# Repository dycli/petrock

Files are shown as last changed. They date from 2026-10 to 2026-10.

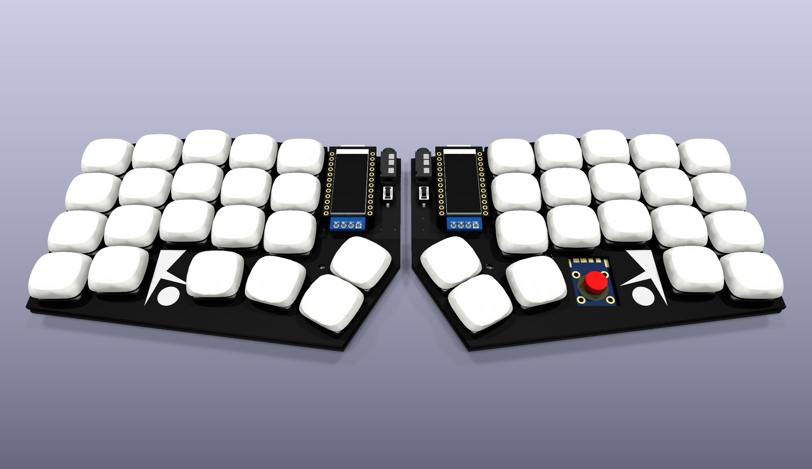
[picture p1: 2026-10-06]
demo/12-assembled.png

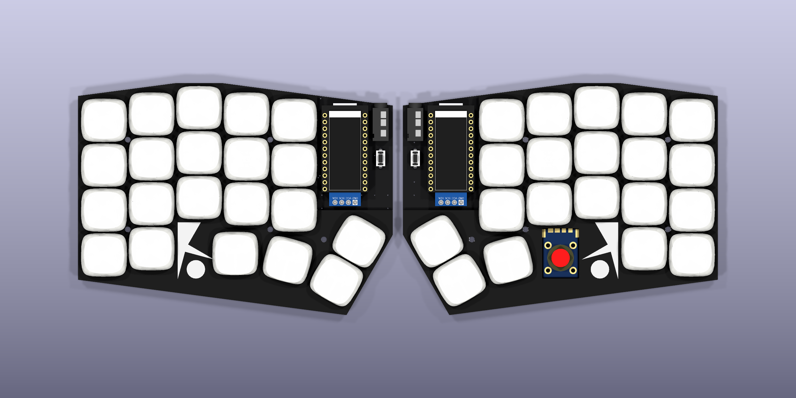
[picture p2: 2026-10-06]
demo/14-assembled-top.png

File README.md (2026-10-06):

# Petrock

A split choc keyboard with a trackpoint in place of an outer thumb key:
**Petrock-41** has one, at the right thumb; **Petrock-40** has one on each half;
**Petrock-42** has none, a key at both outer thumbs.

Based on holykeebs' Corne Choc PCB and plate from
[idank/keyboards](https://github.com/idank/keyboards) (`corne/choc`, commit
f149b9b), licensed CC-BY-SA-4.0. This derivative uses the same licence.

## Changes from the Corne Choc

The board is built from the stock file: its parts move to the new layout, and
every wire is then drawn afresh by rule (see Build). The stock schematic's
connections stay, apart from the thumbs' columns (see Firmware).

- **No lighting.** Every per-key and underglow LED, the LED supply diodes and
  the LED wiring are gone (`tools/no_leds.py`). An RGB version may follow.
- **Exact stagger.** Rows exactly 17 mm apart, each column's top key a whole
  number of 2.37 mm steps below the middle finger's (`tools/stagger.py`;
  stock is off by up to 0.02 mm).
- **Five columns.** The outer pinky column goes. The pinky column moves up to
  one step below the ring column and gains a fourth key (the old outer top
  key); the ring column gains one too (the old outer bottom key). Each joins
  the column wire it lands on, in the thumb row (row 3).
- **Thumb cluster.** Each thumb key turns 15 degrees from its neighbour about a
  hinge where their facing corners sit 0.5 mm apart, starting from the bottom
  inner-index key (`tools/thumbs.py`). The 1.5u inner key becomes two 1u keys;
  the new upper one takes the thumb row's last free column (col 0).
- **Trackpoint.** Sprintek SK8707-01-004 at the outer thumb key: sensor on the
  front, nub centred on where the key was, driver on the back, PS/2 clock and
  data on controller pins 1/2, 3.3 V from the OLED header; sensor A1/A3, controller
  board A2/A4 (`tools/outer_thumb.py`, footprints from `tools/make_footprints.py`).
- **Pins for wireless.** Pins 1/2 are a nice!nano's high-frequency D1/D0, which
  the ZMK PS/2 driver recommends (lower-frequency pins can disturb Bluetooth);
  the TRRS data line moves from pin 2 to pin 11 to free them (`tools/pins.py`).
- **Outline.** Drawn from the keys (`tools/outline.py`): a flat top 1.15 mm
  above the middle column, 7.5-degree slopes to either side, a straight outer
  side, one 7.5-degree bottom edge, and the inner side widened for the upper
  thumb key (`tools/widen.py`). Keycaps sit 1.15 mm from the edge wherever it
  follows them.
- **Controller corner.** Across the strip between the inner index keycaps
  and the inner edge, the controller (a nice!nano's 17.78 mm board) and the
  jack's 6 mm body sit with three even 1.63 mm gaps; each drops until its square
  top corner is 1.15 mm inside the inner slope, like the keycaps. The USB-C and
  the jack's barrel overhang. The reset button sits under the jack
  (`tools/inner_strip.py`).
- The holykeebs and Corne logos and holykeebs' revision stamp are removed; the back
  carries the short hash of the commit the board was built from, between each
  controller's pin rows (`tools/stamp.py`; the build won't stamp uncommitted
  scripts); the board and the switch plates
  carry the Petrock logo with a 7 mm dot in its notch (`tools/logo.py`), and the
  jack, reset button and OLED header have no printed outlines
  (`tools/quiet_silk.py`).
- Five standoffs per half, as stock, placed by geometry (`tools/standoffs.py`):
  four where four keys meet, each at the four keys' centre, forming a 54 x 34 mm
  rectangle (pinky and ring columns, and index and inner index columns, each
  between their top two rows and below their third); and one at the thumbs,
  equally far from its three keycap corners. A key diode may move a fraction to
  make room, if it stays clear. The switch plate has a screw hole over each
  (`tools/plate.py`), as stock.
- Plates regenerated (`tools/plate.py`): the right one (both, on Petrock-40;
  neither, on Petrock-42) has an opening for the trackpoint sensor; a new FR4 bottom plate fits the
  outline.

## Build

`tools/build.sh [single|dual|none]` regenerates a board from the stock file:

1. **Place:** strip the lighting, then move every part to the layout
   (`tools/parts.py drag`).
2. **Route by rule** (`tools/route.py`), as a careful hand would: each column a
   straight line up the front through its switch pins; each row a line along
   the back under its keys, stepping 45 degrees in the gap between columns;
   every diode in the same place beside its key with the same two short links;
   the column wires gathered into an evenly spaced bus in the gap under the
   middle row and fanned into the controller in a staircase; the trackpoint
   wires and power in a bundle up the lane between the middle and index
   columns and along the top edge; every bend 45 degrees, no right angles
   except where a wire joins another. Then ground is poured on both sides and
   stitched together with vias (`tools/stitch.py`).
3. **Check:** the build fails unless DRC finds nothing but the stock
   footprints' library notices and every connection is made.

Then `tools/plates.sh` makes the plates (order the switch plates at 1.2 mm,
which choc switches clip into; the main board and bottom plate at 1.6 mm; all
in HASL, the cheapest finish: the trackpoint driver's pads are hand-soldered
and wide enough that ENIG's flatness isn't needed)
and the 1:1 printout (print it with
scaling off, e.g. `lp -o print-scaling=none`). `tools/fab.sh [single|dual|none]`
writes Gerber and drill zips and JLC's assembly BOM and placement (diodes and
hot-swap sockets) to `fab/`; `tools/demo.sh` renders `demo/`. All need KiCad 10.

Outputs: `pcb/petrock-41*.kicad_pcb` and `pcb/bottom.kicad_pcb`;
`pcb/dual/petrock-40*.kicad_pcb` and `pcb/dual/bottom.kicad_pcb`;
`pcb/none/petrock-42*.kicad_pcb` and `pcb/none/bottom.kicad_pcb`.

## Assembly

The stack, per standoff: a top screw through the switch plate's 2.1 mm hole
into a spacer that passes through the main board's 3.1 mm hole down to the
bottom plate, where a bottom screw holds it. The switch plate and bottom plate
clamp the spacers; the main board hangs from the switches (clipped into the
plate, pins in the hot-swap sockets), 1.0 mm under the plate.

- 10 round M2 x 5 mm female-female spacers, 3.0 mm across (knurled brass ones
  are common; hex ones don't pass the 3.1 mm holes). 5 mm, not holykeebs' 4 mm:
  it leaves 2.4 mm under the main board for the sockets (1.85 mm) and the
  trackpoint drivers (about 2.1 mm).
- Top screws (they sit on the plate, beside the switches): the four where four
  keys meet sit between switch housings (15 mm square on an 18 x 17 mm grid),
  so their heads must be about 3.0 mm across or less: M2 low small-head socket
  screws (e.g. MISUMI's; check the listed head diameter), or M1.6 socket caps
  (3.0 mm heads) with M1.6 spacers at those four. The thumb one and the 10
  underneath: ordinary low M2 x 3 mm screws (e.g. ISO 7380, holykeebs').
- Order: spacers up through the main board, bottom plate on; switch plate on
  and its screws in; then the switches, which draw the main board up as they seat.
- Rubber feet: near the standoffs, and two along the bottom edge (by the outer
  corner and under the trackpoint), which has no standoff.

## Firmware

- Matrix (each half, right with `_r` nets): rows 0-2 are the three full rows,
  columns 1-5 pinky to inner index. Row 3 is the bottom pinky key (col 1), the
  bottom ring key (col 2) and the thumbs, outer to inner: col 3, col 4, col 5.
  Col 0 is unused, except on a half with four thumbs (the 41's left, both of
  the 42's): there the extra outermost one (in the trackpoint's place) is col
  3, the next two col 4 and col 5, and the innermost col 0.
- Wired (QMK, RP2040 Pro Micro): split serial on pin 11 (`SOFT_SERIAL_PIN GP8`,
  PIO driver); PS/2 `PS2_CLOCK_PIN GP0`, `PS2_DATA_PIN GP1` (PIO driver).
- Wireless (ZMK, nice!nano): PS/2 clock D1 (P0.06), data D0 (P0.08), e.g. with
  infused-kim's PS/2 mouse driver; the trackpoint's driver board resets itself,
  so no reset pin. It draws power from the controller's VCC pin, which ZMK's
  external-power control switches off in sleep. The battery solders to the
  nice!nano's B+/B- pads (no switch on the board). The jack isn't used.
- The sensor's pad edge faces the controller (if the axes come out turned,
  rotate them in firmware). No RGB.

## Open items

- **Driver footprint:** Sprintek doesn't draw the detached driver on its own.
  Its outline and sensor-link pads follow the integrated-module drawing. Its
  host pins disagree between the drawing (1.80 mm pitch) and holykeebs'
  product photos (1.72 mm), so their pads fit both: 1.758 mm pitch about the
  row's shared middle, every pin within 0.21 mm of its pad's centre either
  way. Check a real driver against the footprint before ordering boards.
- **Under-board height:** check that the driver (about 2 mm) clears the
  bottom plate.
- **Standoff length** for the plate/PCB/bottom sandwich (M2 3 mm both sides
  expected for the 1.6 mm FR4 bottom).
- **Schematic:** still the Corne Choc's.

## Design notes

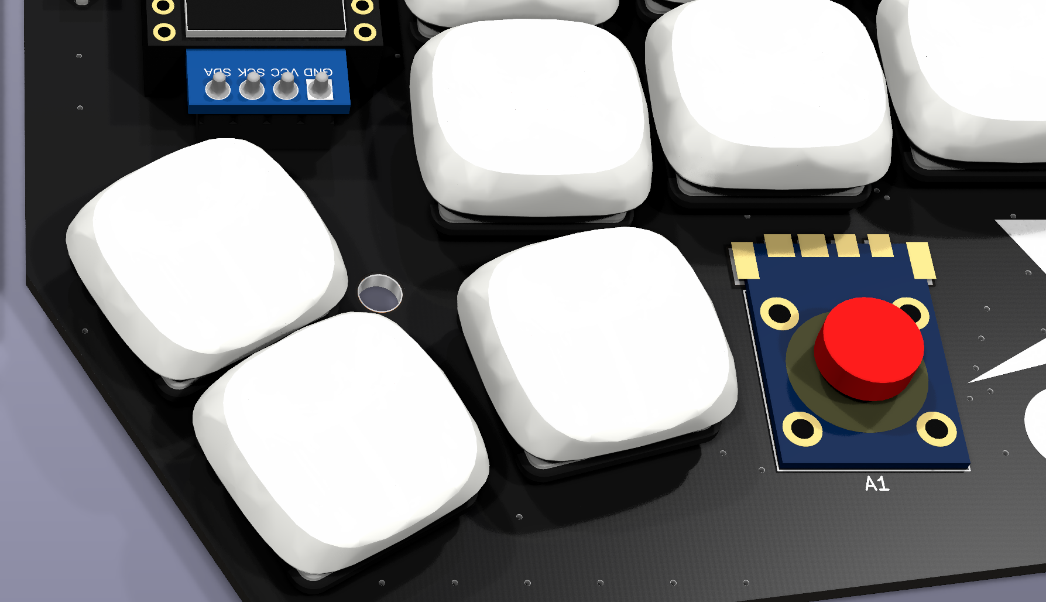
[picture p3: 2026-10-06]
demo/03-trackpoint-closeup.png

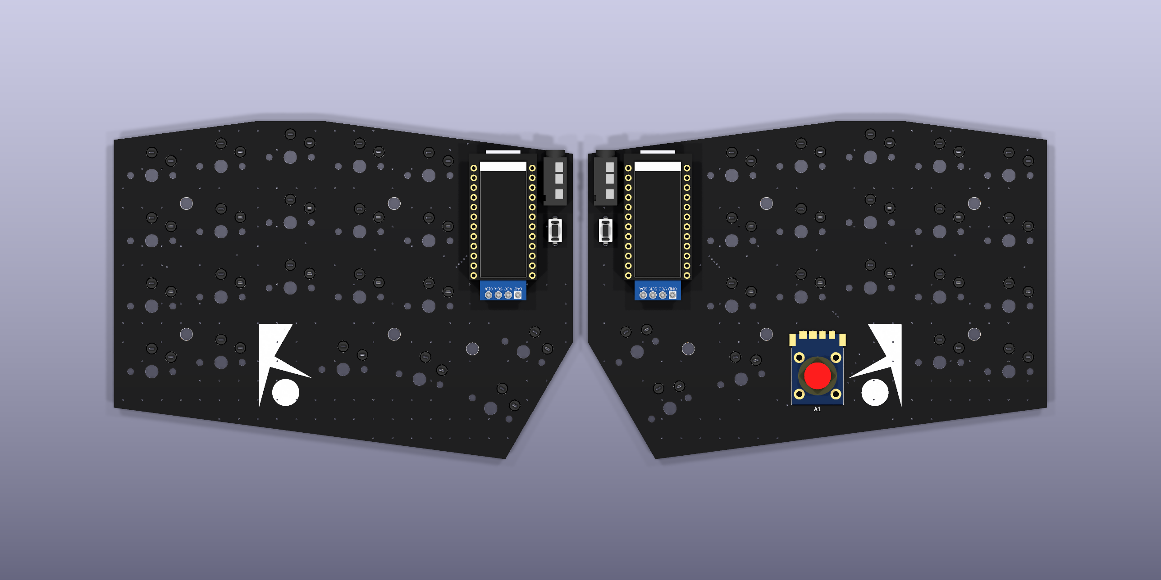
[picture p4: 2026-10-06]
demo/04-bare-front.png

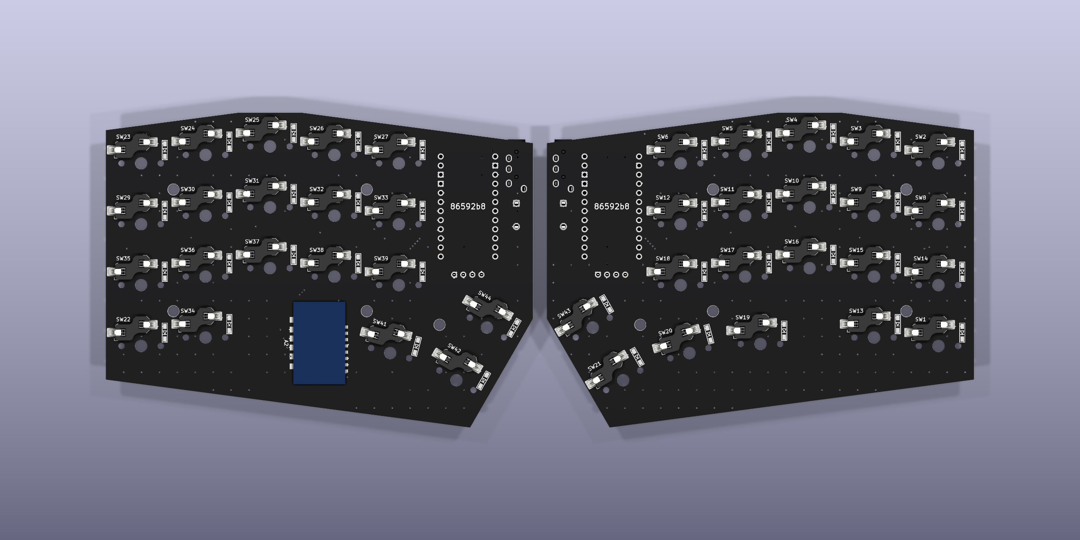
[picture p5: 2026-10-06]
demo/05-bare-back.png

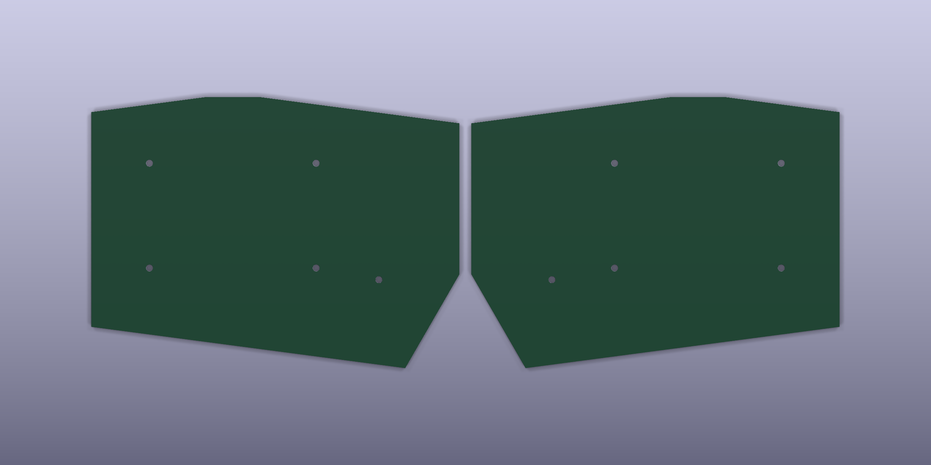
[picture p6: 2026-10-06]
demo/08-bottom-plate.png

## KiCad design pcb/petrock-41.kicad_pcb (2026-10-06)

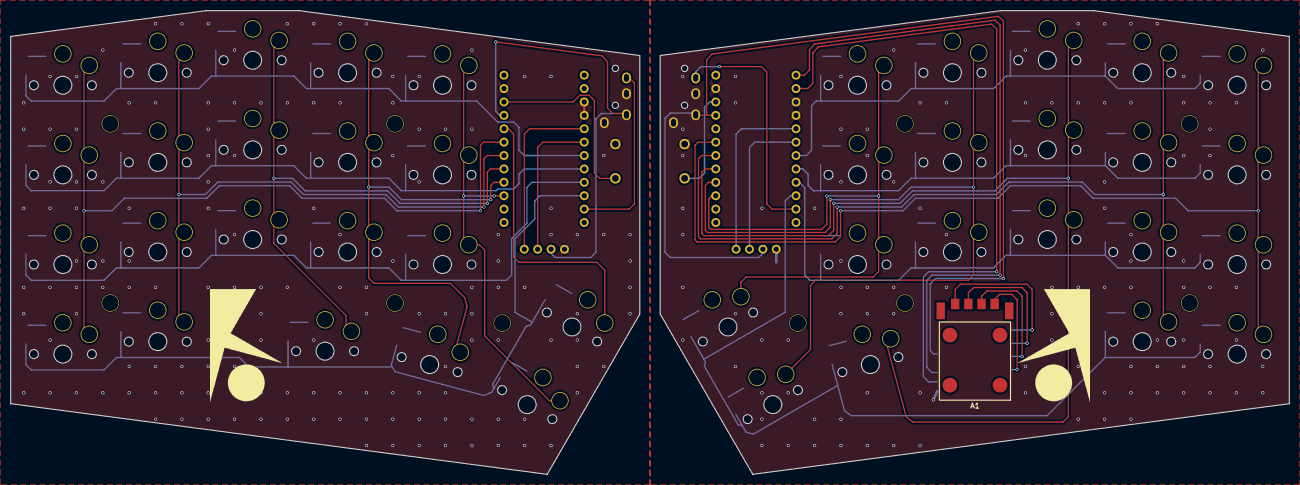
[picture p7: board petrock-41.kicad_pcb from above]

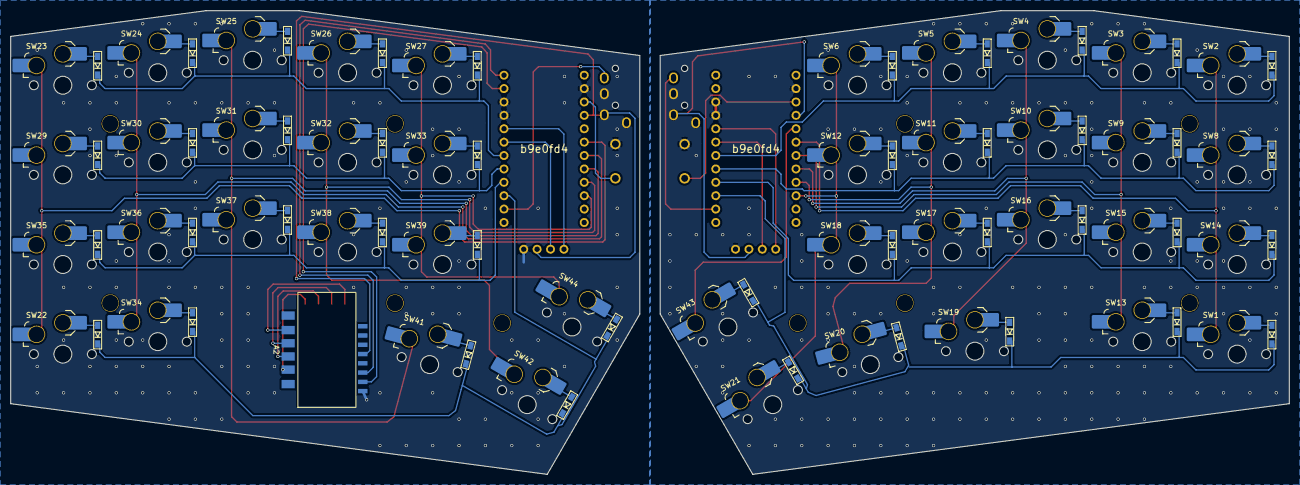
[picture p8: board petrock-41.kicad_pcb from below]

Board: 2 copper layers, 242.5 x 87.9 mm, 100 parts (87 on the bottom side), 78 nets.

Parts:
A1: SK8707-01 sensor; SK8707-01_sensor
A2: SK8707-01 driver; SK8707-01_driver
D1, D2, D3, D4, D5, D6, D8, D9, D10, D11, D12, D13, D14, D15, D16, D17, D18, D19, D20, D21, D22, D23, D24, D25, D26, D27, D29, D30, D31, D32, D33, D34, D35, D36, D37, D38, D39, D41, D42, D45, D46: D; D3_SMD_v2
J1, J3: MJ-4PP-9; MJ-4PP-9_1side
J2, J4: OLED; OLED_1side_1mm_holes
RSW1, RSW2: SW_PUSH; ResetSW_1side
SW1, SW2, SW3, SW4, SW5, SW6, SW8, SW9, SW10, SW11, SW12, SW13, SW14, SW15, SW16, SW17, SW18, SW19, SW20, SW21, SW22, SW23, SW24, SW25, SW26, SW27, SW29, SW30, SW31, SW32, SW33, SW34, SW35, SW36, SW37, SW38, SW39, SW41, SW42, SW43, SW44: SW_PUSH; SW_choc_v1_HS_CPG135001S30_1u
U1, U2: ProMicro; ProMicro_1mm_holes
h2, h2#2, h2#3, h2#4, h2#5, h2#6, h2#7, h2#8: h2; M2_SPACER

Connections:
GND: J1.C, J2.4, RSW1.2, U1.3 (GND), U1.4 (GND), U1.23 (GND)
GNDA: A2.1, J3.C, J4.4, RSW2.2, U2.3 (GND), U2.4 (GND), U2.23 (GND)
unnamed: D1.2 (A), SW1.2
unnamed: D2.2 (A), SW2.2
unnamed: D3.2 (A), SW3.2
unnamed: D4.2 (A), SW4.2
unnamed: D5.2 (A), SW5.2
unnamed: D6.2 (A), SW6.2
unnamed: D8.2 (A), SW8.2
unnamed: D9.2 (A), SW9.2
unnamed: D10.2 (A), SW10.2
unnamed: D11.2 (A), SW11.2
unnamed: D12.2 (A), SW12.2
unnamed: D13.2 (A), SW13.2
unnamed: D14.2 (A), SW14.2
unnamed: D15.2 (A), SW15.2
unnamed: D16.2 (A), SW16.2
unnamed: D17.2 (A), SW17.2
unnamed: D18.2 (A), SW18.2
unnamed: D19.2 (A), SW19.2
unnamed: D20.2 (A), SW20.2
unnamed: D21.2 (A), SW21.2
unnamed: D22.2 (A), SW22.2
unnamed: D23.2 (A), SW23.2
unnamed: D24.2 (A), SW24.2
unnamed: D25.2 (A), SW25.2
unnamed: D26.2 (A), SW26.2
unnamed: D27.2 (A), SW27.2
unnamed: D29.2 (A), SW29.2
unnamed: D30.2 (A), SW30.2
unnamed: D31.2 (A), SW31.2
unnamed: D32.2 (A), SW32.2
unnamed: D33.2 (A), SW33.2
unnamed: D34.2 (A), SW34.2
unnamed: D35.2 (A), SW35.2
unnamed: D36.2 (A), SW36.2
unnamed: D37.2 (A), SW37.2
unnamed: D38.2 (A), SW38.2
unnamed: D39.2 (A), SW39.2
unnamed: D41.2 (A), SW41.2
unnamed: D42.2 (A), SW42.2
unnamed: D45.2 (A), SW43.2
unnamed: D46.2 (A), SW44.2
SCL: J2.2, U1.6 (3/D0/SCL)
SCL_r: J4.2, U2.6 (3/D0/SCL)
SDA: J2.1, U1.5 (2/D1/SDA)
SDA_r: J4.1, U2.5 (2/D1/SDA)
TP_CLK: A2.3, U2.1 (TX0/D3)
TP_DATA: A2.2, U2.2 (RX1/D2)
TP_S1: A1.S1, A2.S1
TP_S2: A1.S2, A2.S2
TP_S3: A1.S3, A2.S3
TP_S4: A1.S4, A2.S4
VCC: J1.D, J2.3, U1.21 (VCC)
VDD: A2.5, J3.D, J4.3, U2.21 (VCC)
col0: SW43.1, U1.20 (F4/A3)
col1: SW1.1, SW2.1, SW8.1, SW14.1, U1.19 (F5/A2)
col1_r: SW22.1, SW23.1, SW29.1, SW35.1, U2.19 (F5/A2)
col2: SW3.1, SW9.1, SW13.1, SW15.1, U1.18 (F6/A1)
col2_r: SW24.1, SW30.1, SW34.1, SW36.1, U2.18 (F6/A1)
col3: SW4.1, SW10.1, SW16.1, SW19.1, U1.17 (F7/A0)
col3_r: SW25.1, SW31.1, SW37.1, SW41.1, U2.17 (F7/A0)
col4: SW5.1, SW11.1, SW17.1, SW20.1, U1.16 (B1/15)
col4_r: SW26.1, SW32.1, SW38.1, SW42.1, U2.16 (B1/15)
col5: SW6.1, SW12.1, SW18.1, SW21.1, U1.15 (B3/14)
col5_r: SW27.1, SW33.1, SW39.1, SW44.1, U2.15 (B3/14)
data: J1.B, U1.11 (8/B4)
data_r: J3.B, U2.11 (8/B4)
reset: RSW1.1, U1.22 (RST)
reset_r: RSW2.1, U2.22 (RST)
row0: D2.1 (K), D3.1 (K), D4.1 (K), D5.1 (K), D6.1 (K), U1.7 (4/D4)
row0_r: D23.1 (K), D24.1 (K), D25.1 (K), D26.1 (K), D27.1 (K), U2.7 (4/D4)
row1: D8.1 (K), D9.1 (K), D10.1 (K), D11.1 (K), D12.1 (K), U1.8 (5/C6)
row1_r: D29.1 (K), D30.1 (K), D31.1 (K), D32.1 (K), D33.1 (K), U2.8 (5/C6)
row2: D14.1 (K), D15.1 (K), D16.1 (K), D17.1 (K), D18.1 (K), U1.9 (6/D7)
row2_r: D35.1 (K), D36.1 (K), D37.1 (K), D38.1 (K), D39.1 (K), U2.9 (6/D7)
row3: D1.1 (K), D13.1 (K), D19.1 (K), D20.1 (K), D21.1 (K), D45.1 (K), U1.10 (7/E6)
row3_r: D22.1 (K), D34.1 (K), D41.1 (K), D42.1 (K), D46.1 (K), U2.10 (7/E6)

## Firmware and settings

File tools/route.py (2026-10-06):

"""Route the board by rule, as by hand: columns straight up the front, rows
along the back under each key, the same short diode links on every key, and
the column wires gathered into an even bus to the controller. Handles both
boards: the 40 (trackpoint on each half) and the 41 (extra thumb key on the left).

usage: route.py IN OUT
"""
import os
import sys

import pcbnew

SRC, OUT = sys.argv[1:3]
b = pcbnew.LoadBoard(SRC)                # bare of tracks (tools/clear_copper.py): every wire is drawn here
MM = pcbnew.FromMM
F, B = pcbnew.F_Cu, pcbnew.B_Cu
W = 0.25                 # signal width
ROW_DY = 3.0             # row line below each key centre
COL_DX = 4.0             # column line right of each key centre (passes left of the side hole)
BUS_DY = 4.4             # first bus wire below the row-0 key centre
BUS_PITCH = 0.65


def fp(ref):
    return b.FindFootprintByReference(ref)


def pad(ref, num, tht=None):
    """Position (mm) of a part's pad; tht=True picks the plated hole one."""
    for p in fp(ref).Pads():
        if p.GetNumber() == num and (tht is None or (p.GetAttribute() == pcbnew.PAD_ATTRIB_PTH) == tht):
            return pcbnew.ToMM(p.GetPosition().x), pcbnew.ToMM(p.GetPosition().y)
    raise KeyError((ref, num))


def net(ref, num):
    for p in fp(ref).Pads():
        if p.GetNumber() == num:
            return p.GetNet()


def track(n, layer, pts, w=W):
    for (x1, y1), (x2, y2) in zip(pts, pts[1:]):
        if (x1, y1) == (x2, y2):
            continue
        t = pcbnew.PCB_TRACK(b)
        t.SetStart(pcbnew.VECTOR2I(MM(x1), MM(y1)))
        t.SetEnd(pcbnew.VECTOR2I(MM(x2), MM(y2)))
        t.SetWidth(MM(w))
        t.SetLayer(layer)
        t.SetNet(n)
        b.Add(t)


def via(n, p):
    v = pcbnew.PCB_VIA(b)
    v.SetPosition(pcbnew.VECTOR2I(MM(p[0]), MM(p[1])))
    v.SetWidth(MM(0.6))
    v.SetDrill(MM(0.4))
    v.SetNet(n)
    b.Add(v)


def jog(x0, y0, x1, y1):
    """Horizontal from (x0,y0) to (x1,y1) with one 45-degree step at the end."""
    dy = y1 - y0
    s = 1 if x1 >= x0 else -1
    return [(x0, y0), (x1 - s * abs(dy), y0), (x1, y1)]


import math

DIODE = (-6.6, -3.7)     # diode centre from its key centre: anode within socket pad 2's height, clear of the standoffs


def local(key):
    """Map key-local mm offsets (unrotated key, y down) onto the board."""
    f = fp(key)
    cx, cy = pcbnew.ToMM(f.GetPosition().x), pcbnew.ToMM(f.GetPosition().y)
    t = math.radians(f.GetOrientationDegrees())
    return lambda x, y: (cx + x * math.cos(t) + y * math.sin(t), cy - x * math.sin(t) + y * math.cos(t))


# Every diode in the same place beside its key.
for f in list(b.GetFootprints()):
    r = f.GetReference()
    if not r.startswith("SW") or not net(r, "2").GetNetname().startswith("Net-(D"):
        continue
    an = net(r, "2").GetNetname()
    d = fp(an[len("Net-("):an.index("-A")])
    x, y = local(r)(*DIODE)
    d.SetPosition(pcbnew.VECTOR2I(MM(x), MM(y)))
    d.SetOrientationDegrees(90 + f.GetOrientationDegrees())

DUAL = any(f.GetReference() == "A4" for f in b.GetFootprints())   # a trackpoint on the left (the 40)
RTP = any(f.GetReference() == "A2" for f in b.GetFootprints())    # a trackpoint on the right (the 40 and 41)

# ---- the key matrix of the left half ------------------------------------
# Main keys: socket unrotated, diode to its left. Columns by x, rows by y.
keys = {}
for f in b.GetFootprints():
    r = f.GetReference()
    if r.startswith("SW") and f.GetOrientationDegrees() == 0 and pcbnew.ToMM(f.GetPosition().x) < 155:
        keys[r] = (pcbnew.ToMM(f.GetPosition().x), pcbnew.ToMM(f.GetPosition().y))
diode_of = {}
for r in keys:
    anode = net(r, "2").GetNetname()            # e.g. Net-(D2-A)
    diode_of[r] = anode[len("Net-("):anode.index("-A")]

xs = [round(x, 2) for x, _ in keys.values()]
keys = {r: p for r, p in keys.items() if xs.count(round(p[0], 2)) >= 3}   # the 41's extra thumb has no column
cols = sorted({round(x, 2) for x, _ in keys.values()})
grid = {}                                       # (col, row) -> ref, for rows 0..2
for r, (x, y) in keys.items():
    c = cols.index(round(x, 2))
    grid.setdefault(c, []).append((y, r))
for c in grid:
    grid[c].sort()

main = {}                                       # (c, row) -> ref for the 3 full rows
for c, ys in grid.items():
    for i, (y, r) in enumerate(ys[:3]):
        main[(c, i)] = r

# Diode links: anode straight across to the socket's pad 2; cathode straight
# down to the row line under the key.
for (c, i), r in main.items():
    cx, cy = keys[r]
    d = diode_of[r]
    ax, ay = pad(d, "2")
    kx, ky = pad(d, "1")
    track(net(d, "2"), B, [(ax, ay), (cx - 3.24, ay)])
    track(net(d, "1"), B, [(cx - 7.0, ky), (cx - 7.0, cy + ROW_DY)])

# Rows 0..2: one line under the keys, a 45-degree step between columns.
rows_end = {}
for i in range(3):
    n = net(diode_of[main[(0, i)]], "1")
    pts = []
    for c in range(len(cols)):
        cx, cy = keys[main[(c, i)]]
        y = cy + ROW_DY
        if not pts:
            pts.append((cx - 7.0, y))
        else:                              # a 45-degree step centred on the gap between the keys
            x0, y0 = pts[-1]
            gap = cols[c] - 9.0
            h = abs(y - y0) / 2
            pts += [(gap - h, y0), (gap + h, y), (cx - 7.0, y)]
    rows_end[i] = (n, pts)

# Columns: straight down the front through every switch pin of the column.
for c in range(len(cols)):
    ys = grid[c]
    top, bot = ys[0][1], ys[-1][1]
    x = cols[c] + COL_DX
    n = net(top, "1")
    track(n, F, [(x, pad(top, "1", tht=True)[1]), (x, pad(bot, "1", tht=True)[1])])

# ---- into the controller --------------------------------------------------
U = "U1"


def pin_of(netname):
    for p in fp(U).Pads():
        if p.GetNetname() == netname:
            return pcbnew.ToMM(p.GetPosition().x), pcbnew.ToMM(p.GetPosition().y)
    raise KeyError(netname)


LEFT_PINS = pin_of("col0")[0]            # the controller's pin row facing the keys
GAP = 0.65                               # an even step between neighbouring wires

# Rows: through the gap between two near-side pins, then across underneath the
# controller to their own pin on the far side.
INSIDE = LEFT_PINS + 2.84                # first wire lane inside the controller
for i, (n, pts) in rows_end.items():
    px, py = pin_of(n.GetNetname())
    x, y = pts[-1]
    if i < 2:
        gy = py - 6.35 if i == 0 else py + 3.81      # half way between two near-side pins
        pts += jog(x, y, LEFT_PINS - 1.2, gy)[1:]
        pts += [(INSIDE, gy), (INSIDE, py + (1 if gy > py else -1)), (INSIDE + 1, py), (px, py)]
    else:
        # Below the controller's last pin, then up the inside.
        lane = INSIDE + 1.5 * (i - 1)
        drop = LEFT_PINS + 1.45 + 0.65 * (i - 2)
        pts += [(drop, y), (drop, 95.0)]
        pts += [(lane, 95.0 - (lane - drop)), (lane, py + 1), (lane + 1, py), (px, py)]
    track(n, B, pts)
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

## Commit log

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2026-10-03 Right-thumb trackpoint: widen inner edges, jacks to top edge, module header TP1
    Generated by tools/build.sh from the upstream board. SW42, D42 and the right
    OLED header are removed; TP1 (Pro Micro pattern, pins 5/6/21/23 wired to
    GP2/GP3/3V3/GND) takes the thumb spot. Both halves widen 6.2 mm on the inner
    edge so the TRRS jacks face the top edge beside the controllers. DRC matches
    upstream apart from pre-existing LED cutout warnings.
    [corne choc.kicad_pcb]
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2026-10-03 Trackpoint at the right outer thumb key with an SK8707-01 sensor and driver
    Replaces the earlier holykeebs-module design. The board is stock except at
    SW40: switch, diode and hidden LED removed (RGB chain bridged), sensor on the
    front at the key centre, driver on the back beneath it, PS/2 to U2 pins 11/12
    (GP8/GP9). Routing uses a small grid router; DRC matches upstream apart from
    pre-existing LED-cutout warnings.
    [bottom.kicad_pcb, corne choc plate.kicad_pcb, corne choc.kicad_pcb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]
2026-10-03 Driver footprint from holykeebs' top-view photo: 23 x 14.5 mm, wider host pads
    The photo shows the detached driver is the full 14.5 mm control board and
    confirms the sensor-link pad pitch and order. Driver moved to fit; routes now
    name pads instead of coordinates; router keeps 0.3 mm from holes.
    [corne choc.kicad_pcb]
2026-10-03 v2: wider inner edges, jacks at the top, split inner thumb keys, peaked top edges
    Both halves widen 6.2 mm inward with the TRRS jacks facing the top edge; each
    inner 1.5u thumb becomes two 1u keys at the same angle (new key on col2, with
    diode and LED in the chain); edges sit 0.95 mm from the inner thumb keycaps;
    top edges peak at the middle-finger column. New switch plate and FR4 bottom.
    Routing is DRC-driven (autoconnect + maze); DRC matches upstream apart from
    warnings.
    [bottom.kicad_pcb, corne choc plate.kicad_pcb, corne choc.kicad_pcb]
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2026-10-03 v2.1: thumb arc, key-following edges, roomier trackpoint
    - Thumb keys on one arc on both halves (0/15/30 degrees); the split inner
    keys turn like the others and stack one row apart (tools/thumbs.py).
    - Edge round the thumbs redrawn from the keys: 0.95 mm from the inner
    keycaps, one level line under the middle and outer keys, and a 60-degree
    outer slant cornered off the trackpoint sensor. Halves identical.
    - Trackpoint stem 3.4 mm lower in the same board footprint.
    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
    [bottom.kicad_pcb, corne choc plate right.kicad_pcb, corne choc.kicad_pcb]
2026-10-03 v2.1: 1.15 mm key-to-edge gap, matching switch orientation, LED moves
    - Keycaps sit 1.15 mm from the edge wherever it follows them; outer side
    edges move out, and every hot-swap socket pad clears the edge by 0.33 mm.
    - The left inner thumb keys no longer turn 180 degrees: every switch, and
    every per-key LED, faces the same way.
    - Underglow LED32 and its left twin LED5 move, mirrored, clear of the
    trackpoint driver's hand-soldered pads.
    - Mounting holes for the unused OLED cover removed (tools/strip.py).
    - Plates follow the moved outer edges; renders show both plates fitted.
    - Build: finish pass runs until no dangling copper is left.
    [bottom.kicad_pcb, corne choc plate right.kicad_pcb, corne choc plate.kicad_pcb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]
2026-10-03 v2.1: driver pads per drawing, diagonal plate edge, no-OLED renders
    - Trackpoint driver host pads follow Sprintek's drawing: 1.0 mm wide at
    1.80 mm pitch, leaving 0.8 mm between them for hand soldering.
    - The switch plate carries the upper inner thumb key's top edge straight
    on to its inner edge (2.6 mm clear of the OLED header) instead of a step.
    - Render script gains assembled top-down and no-OLED views.
    [bottom.kicad_pcb, corne choc plate right.kicad_pcb, corne choc plate.kicad_pcb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]
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2026-10-03 Dual-trackpoint variant (build.sh dual) alongside the single
    - tools/outer_thumb.py places a trackpoint on either half (one half per run);
    the dual build puts one on each outer thumb key, into pcb/dual/ and
    fab/dual/, with one switch-plate design (sensor opening) for both halves.
    - Left trackpoint: same pins (GP8/GP9) and 3.3 V source as the right.
    - Router keeps 0.3 mm from other copper (diagonals had cut inside 0.2 mm);
    each driver's ground pin joins by track, not by the pour.
    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
    [bottom.kicad_pcb, corne choc dual plate.kicad_pcb, corne choc dual.kicad_pcb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]
2026-10-03 Thumb cluster on the index-aligned arc, wider inner edge, 15-degree marks
    - The thumb cluster sits 1.37 mm further in and 0.98 mm higher, so the middle
    thumb key meets the bottom index key the way it meets the inner key (same
    corner gap, opening at 15 degrees); the trackpoint moves with it.
    - The inner straight edge moves out by what the upper inner thumb key needs
    to keep the 1.15 mm gap (6.92 mm in all); jacks stay centred in the strip,
    1.24 mm from the controller pins.
    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
    [bottom.kicad_pcb, corne choc dual plate.kicad_pcb, corne choc dual.kicad_pcb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]
2026-10-04 Petrock-41/40: rebuild from the stock Corne Choc with minimal copper change
    Parts move to the final layout dragging their copper, crowded copper is
    nudged inside the new edge, only copper off the board or in a clash the
    stock board didn't have is cut, and only what is then open is routed,
    never ripping up stock copper. About 60% of the stock copper stays.
    Lighting is dropped for this build (no_leds.py). The pinky and ring
    fourth keys join the column wire they land on (row 3); the upper inner
    thumb takes col 0. The trackpoint reset line, LED power switch,
    underglow grid and 15-degree marks are gone, with the old rip-up and
    prune steps. Boards renamed: petrock-41 (single), petrock-40 (dual).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
    [bottom.kicad_pcb, corne choc dual plate.kicad_pcb, corne choc dual.kicad_pcb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]
2026-10-05 Wireless-ready pins, last-resort routing, fresh renders
    The trackpoint moves to controller pins 1/2 (a nice!nano's high-frequency
    D1/D0, as the ZMK PS/2 driver recommends) and each TRRS data line to pin
    11 (tools/pins.py); wired QMK on an RP2040 handles both. A connection
    boxed in by stock copper may now rip it up as a last resort, so both
    boards route fully. README documents the wired and wireless pinouts.
    [bottom.kicad_pcb, petrock-40 plate.kicad_pcb, petrock-40.kicad_pcb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]
2026-10-05 Hand-solder gaps of 0.9 mm, pinned tools, clean pours
    Every hand-soldered pad now leaves at least 0.9 mm to the next (headers
    stay at the standard 2.54 mm pitch): trackpoint sensor-link pads 1.6 mm
    wide, driver host pads 0.9 mm, TRRS slot pads 2.1 mm long.
    Pours drop floating islands. The last-resort routing pass repeats until
    nothing is open. KiCad, Python and friends are pinned as GC roots in
    .nix/ (bin/setup), so garbage collection can't break the build again.
    [bottom.kicad_pcb, petrock-40 plate.kicad_pcb, petrock-40.kicad_pcb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]
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2026-10-05 Five standoffs per half, logo on the board, plain controller corner
    The standoff the outer pinky column lost moves to where the pinky and ring
    columns meet, so the outer top corner is supported again (10 in all). The
    logo is back on the board's silkscreen. The jack, reset button and OLED
    header lose their printed outlines. The plate's opening by the controller
    now starts at the inner index keycap line instead of the stock plate's
    fixed edge, clearing the moved controller's sockets by 1.66 mm. The board
    records its ENIG finish; renders can hide the jack and reset ("wireless").
    [bottom.kicad_pcb, petrock-40 plate.kicad_pcb, petrock-40.kicad_pcb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]
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2026-10-05 Jack pads masked tight, version stamp, A1-A4 for the trackpoint parts
    The stock jack footprint's solder-mask openings showed bare ground beside
    the supply pad, where a hand-soldered bridge would short it: the jack pads'
    mask opening now matches the pad (no solder-mask bridges left; DRC has no
    errors). holykeebs' revision stamp gives way to ours (name, version,
    repository) on the back between the controller's pin rows. The trackpoint
    sensor and controller boards become A1-A4 (assemblies), not TP (test point).
    [petrock-40.kicad_pcb, petrock-41.kicad_pcb]
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2026-10-06 Route every wire by rule (tools/route.py) instead of reusing stock copper
    Columns straight up the front, rows under the keys on the back, identical
    diode links on every key, an even column bus fanned into the controller,
    trackpoint wires and power along the top edge, 45-degree bends throughout;
    ground poured on both sides and stitched (tools/stitch.py). Thumbs move to
    the middle/index/inner columns; col 0 only serves the 41's fourth left thumb.
    The build now fails on any DRC error or open connection. Removes the old
    trim-and-patch router.
    [route.py]
2026-10-06 Clear the placed board's copper in its own step: pcbnew's Python crashes if a process works on after removing tracks
    [route.py]
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
